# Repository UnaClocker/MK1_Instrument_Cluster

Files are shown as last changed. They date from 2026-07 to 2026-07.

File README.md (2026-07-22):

This code cannot be copyrighted, as it was entirely vibe coded via AI, Gemini to be specific. 
The circuit board was based on this design and physically made to fit with STL files which are included. The circuit board is licensed Creative Commons - Attribution.
The STLs were created by me, by hand, in TinkerCAD. They are licensed Create Commons - Attribution.

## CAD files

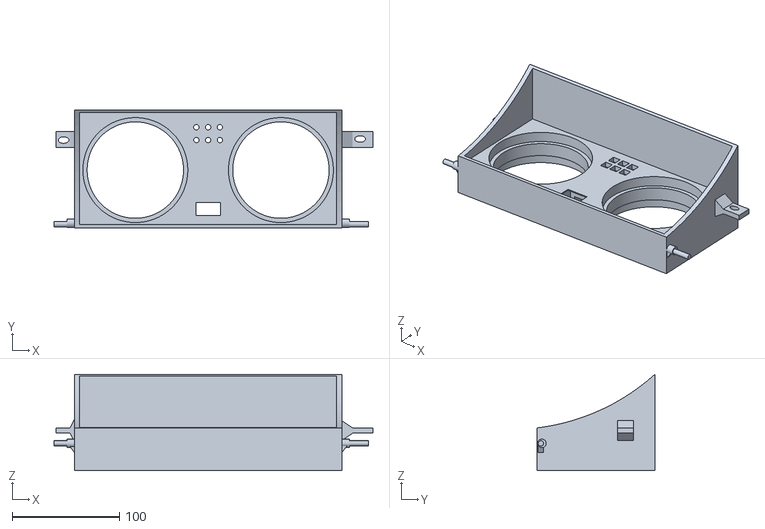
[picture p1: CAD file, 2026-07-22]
MK1 Instrument Cluster (6).stl
298.0 x 110.0 x 90.0

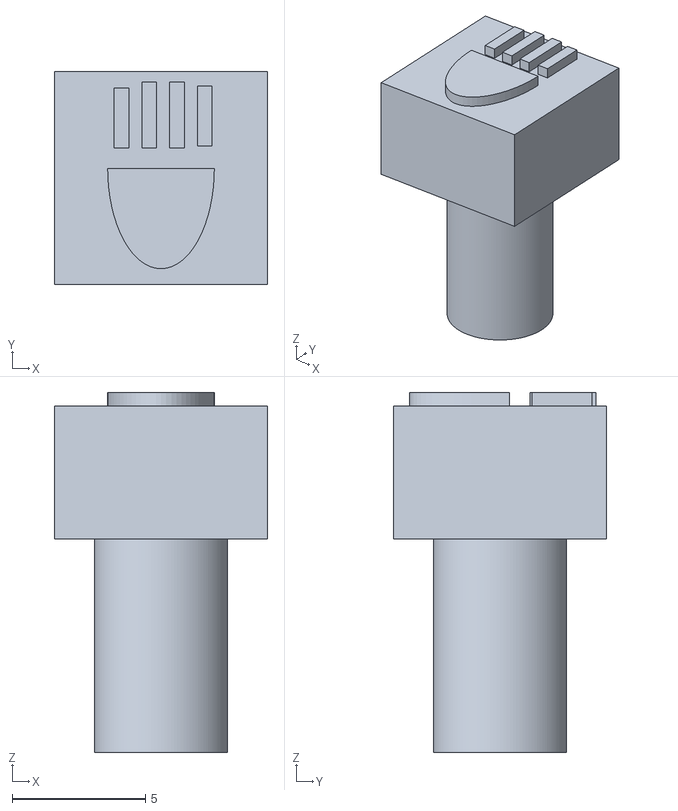
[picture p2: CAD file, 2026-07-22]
High_Beam_Indicators.stl
8.00 x 8.00 x 13.5

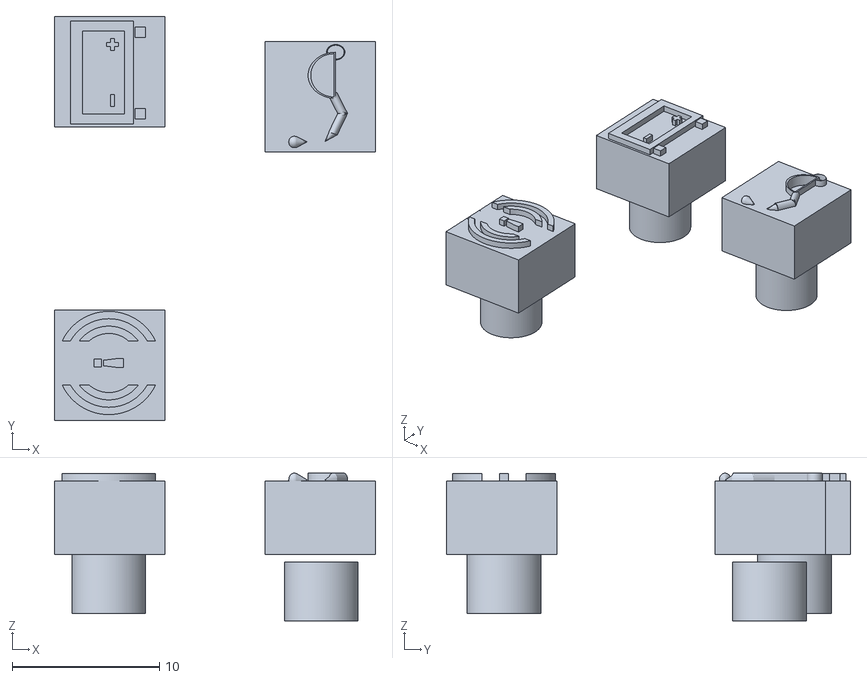
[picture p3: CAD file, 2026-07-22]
Warning_Indicators.stl
21.8 x 27.4 x 10.0

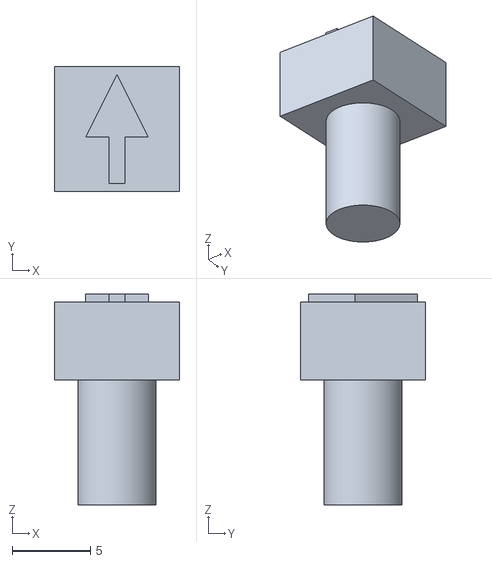
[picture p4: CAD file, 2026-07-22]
Blinker_Indicator.stl
8.00 x 8.00 x 13.5

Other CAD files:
Glowplug_Indicators.stl

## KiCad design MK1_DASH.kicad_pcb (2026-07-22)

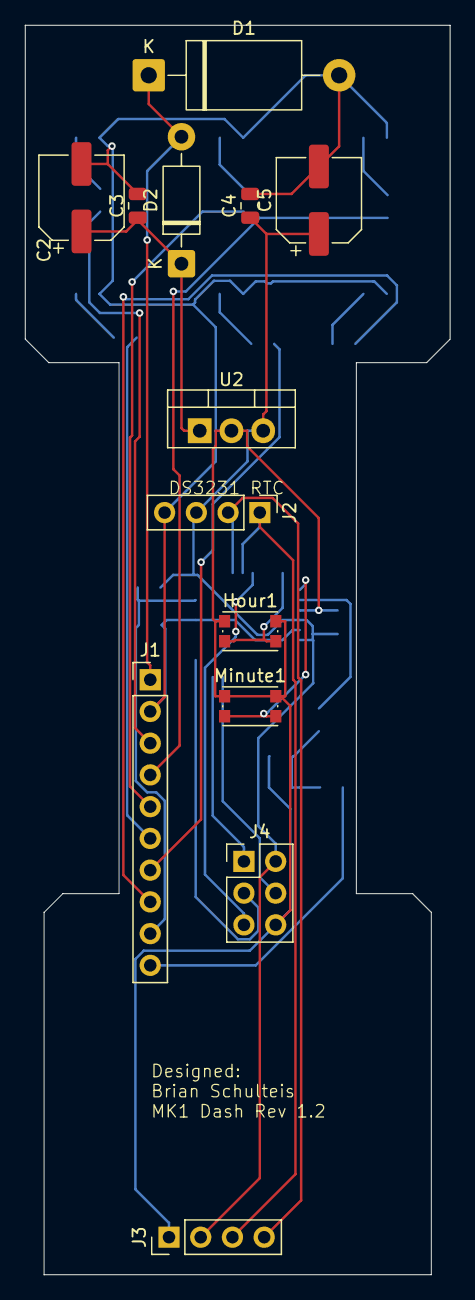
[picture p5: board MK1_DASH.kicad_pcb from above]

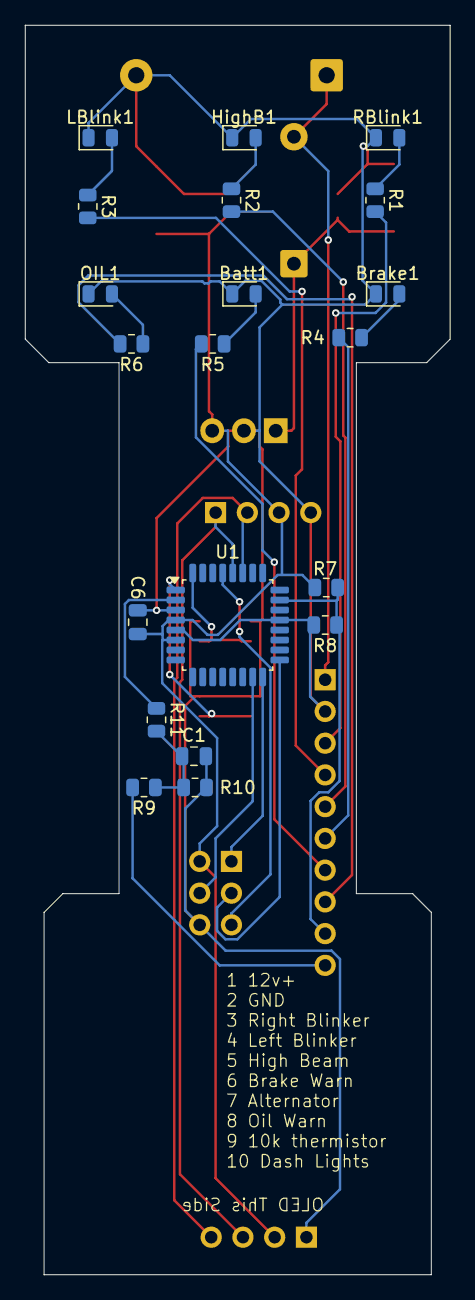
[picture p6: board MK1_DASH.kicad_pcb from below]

Board: 2 copper layers, 34.0 x 100.0 mm, 33 parts (20 on the bottom side), 28 nets.

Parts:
Batt1: LED; LED_0805_2012Metric
Brake1: LED; LED_0805_2012Metric
C1, C3, C4, C6: .1uF; C_0805_2012Metric
C2: 50uF 50v; CP_Elec_6.3x4.5
C5: 10uF 16v; CP_Elec_6.3x4.5
D1: SA18A; D_DO-201AE_P15.24mm_Horizontal
D2: 1N4007; D_DO-41_SOD81_P10.16mm_Horizontal
HighB1: LED; LED_0805_2012Metric
Hour1: SW_Push; SW_Push_1P1T_NO_CK_KMR2
J1: Conn_01x10; PinHeader_1x10_P2.54mm_Vertical
J2: RTC; PinHeader_1x04_P2.54mm_Vertical
J3: OLED; PinHeader_1x04_P2.54mm_Vertical
J4: AVR-ISP-6; PinHeader_2x03_P2.54mm_Vertical
LBlink1: LED; LED_0805_2012Metric
Minute1: SW_Push; SW_Push_1P1T_NO_CK_KMR2
OIL1: LED; LED_0805_2012Metric
R1, R2, R3: 4.7K; R_0805_2012Metric
R4, R5, R6: 3.3K; R_0805_2012Metric
R7, R8, R9: 10k; R_0805_2012Metric
R10: 4.7k; R_0805_2012Metric
R11: 1k; R_0805_2012Metric
RBlink1: LED; LED_0805_2012Metric
U1: ATmega328-A; TQFP-32_7x7mm_P0.8mm
U2: LM7805_TO220; TO-220-3_Vertical

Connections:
/Alternator: J1.7, R5.2
/Battery +: D1.1 (A1), D2.2 (A), J1.1
/Brake: J1.6, R4.2
/Dim: R11.1, U1.2 (PD4)
/High Beam: J1.5, R2.2
/Hour: Hour1.2, U1.32 (PD2)
/L Blinker: J1.4, R3.2
/MISO: J4.1 (MISO), U1.16 (PB4)
/MOSI: J4.4 (MOSI), U1.15 (PB3)
/Minute: Minute1.2, U1.1 (PD3)
/Oil: J1.8, R6.2
/Parking Lights: J1.10, R9.2
/R Blinker: J1.3, R1.2
/RST: J4.5 (~RST), U1.29 (~RESET/PC6)
/SCK: J4.3 (SCK), U1.17 (PB5)
/SCL: J2.1, J3.3, U1.28 (PC5)
/SDA: J2.2, J3.4, U1.27 (PC4)
/Temp: J1.9, R7.1, R8.1, U1.23 (PC0)
GND: Batt1.1 (K), Brake1.1 (K), C1.2, C2.2, C3.2, C4.2, C5.2, C6.2, D1.2 (A2), HighB1.1 (K), Hour1.1, J1.2, J2.4, J3.1, J4.6 (GND), LBlink1.1 (K), Minute1.1, OIL1.1 (K), R8.2, R10.2, RBlink1.1 (K), U1.3 (GND), U1.5 (GND), U1.21 (GND), U2.2 (GND)
unnamed: Batt1.2 (A), R5.1
unnamed: Brake1.2 (A), R4.1
unnamed: C1.1, R9.1, R10.1, R11.2
unnamed: C2.1, C3.1, D2.1 (K), U2.1 (VI)
unnamed: HighB1.2 (A), R2.1
unnamed: LBlink1.2 (A), R3.1
unnamed: OIL1.2 (A), R6.1
unnamed: R1.1, RBlink1.2 (A)
VCC: C4.1, C5.1, C6.1, J2.3, J3.2, J4.2 (VCC), R7.2, U1.4 (VCC), U1.6 (VCC), U2.3 (VO)

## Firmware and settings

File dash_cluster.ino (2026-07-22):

#include <Wire.h>
#include <U8g2lib.h>
#include <RTClib.h>

// U8G2_R2 flips the display 180 degrees
U8G2_SSD1306_128X64_NONAME_F_HW_I2C u8g2(U8G2_R2, /* reset=*/ U8X8_PIN_NONE);

// Initialize the DS3231 RTC
RTC_DS3231 rtc;

// Hardware Pins
const int BTN_HOUR = 2;
const int BTN_MIN = 3;
const int PIN_DIM = 4; // NEW: Low = Dim (1), High = Bright (255)

// Thermistor Parameters
const int THERMISTOR_PIN = A0;
const float SERIES_RESISTOR = 10000.0; 
const float NOMINAL_RESISTANCE = 10000.0; 
const float NOMINAL_TEMPERATURE = 25.0; 
const float B_COEFFICIENT = 3950.0; 
const float ADC_MAX = 1023.0;

// Timing Variables
unsigned long lastTempRead = 0;
const unsigned long tempInterval = 10000; // Read temp every 10 seconds
float currentTempF = 0.0;

// Time Modification Variables
bool isSettingTime = false;
unsigned long lastButtonPressTime = 0;
const unsigned long saveTimeout = 10000; 

// In-memory clock state for editing
int editHour = 0;
int editMinute = 0;
int editSecond = 0;
int editYear = 2026;
int editMonth = 7;
int editDay = 14;

// Simple state tracking for debouncing buttons and dimming
bool lastHourState = HIGH;
bool lastMinState = HIGH;
int currentBrightness = 255;

void setup() {
  pinMode(BTN_HOUR, INPUT_PULLUP);
  pinMode(BTN_MIN, INPUT_PULLUP);
  
  // NEW: Configure dimming pin with an internal pull-up.
  // If left unconnected, it stays HIGH (bright). Grounding this pin triggers dim state.
  pinMode(PIN_DIM, INPUT_PULLUP);

  u8g2.begin();

  Wire.setClock(100000);

  // Show the VW Splash Screen for 3 seconds on startup
  showVWSplashScreen();
}

void loop() {
  unsigned long currentMillis = millis();

  // 1. Handle Dimming Input
  // If PIN_DIM is pulled LOW (active), dim the screen to 1. Otherwise, keep it at 255.
  int targetBrightness = (digitalRead(PIN_DIM) == LOW) ? 1 : 255;
  if (targetBrightness != currentBrightness) {
    currentBrightness = targetBrightness;
    if (targetBrightness==255) {
      setNormalBright();
    } else {
      setUltraDim();
    }
  }

  // 2. Read temperature at defined intervals
  if (currentMillis - lastTempRead >= tempInterval || lastTempRead == 0) {
    lastTempRead = currentMillis;
    currentTempF = readTemperatureF();
  }

  // 3. Fetch the current time
  int displayHour = 0;
  int displayMinute = 0;

  if (!isSettingTime) {
    DateTime now = rtc.now();
    displayHour = now.hour();
    displayMinute = now.minute();
  } else {
    displayHour = editHour;
    displayMinute = editMinute;

    if (currentMillis - lastButtonPressTime >= saveTimeout) {
      rtc.adjust(DateTime(editYear, editMonth, editDay, editHour, editMinute, 0));
      isSettingTime = false;
    }
  }

  // 4. Scan Buttons (Active Low - pressed is LOW)
  bool currentHourState = digitalRead(BTN_HOUR);
  bool currentMinState = digitalRead(BTN_MIN);

  if (currentHourState == LOW && lastHourState == HIGH) {
    delay(50); 
    if (digitalRead(BTN_HOUR) == LOW) {
      if (!isSettingTime) {
        enterEditMode();
      }
      editHour = (editHour + 1) % 24; 
      lastButtonPressTime = currentMillis;
    }
  }

  if (currentMinState == LOW && lastMinState == HIGH) {
    delay(50); 
    if (digitalRead(BTN_MIN) == LOW) {
      if (!isSettingTime) {
        enterEditMode();
      }
      editMinute = (editMinute + 1) % 60; 
      lastButtonPressTime = currentMillis;
    }
  }

  lastHourState = currentHourState;
  lastMinState = currentMinState;

  // 5. Render Layout (Page Buffer Mode)
  u8g2.clearBuffer();
  
    // ----------------------------------------------------
    // Draw Corner Temperature (Top-Right)
    // ----------------------------------------------------
    u8g2.setFont(u8g2_font_7x14_tr); // Large 14px font
    char tempBuffer[8];
    dtostrf(currentTempF, 2, 0, tempBuffer);
    strcat(tempBuffer, "F");
    
    u8g2.drawStr(104, 13, tempBuffer);
    u8g2.drawCircle(98, 5, 1); // Aligned degree symbol

    // If setting time, draw an indicator on the screen
    if (isSettingTime) {
      u8g2.setFont(u8g2_font_5x7_tr); 
      u8g2.drawStr(4, 8, "SET TIME");
    }

    // ----------------------------------------------------
    // Draw Centered Time (HH:MM)
    // ----------------------------------------------------
    u8g2.setFont(u8g2_font_logisoso42_tn);
    char timeBuffer[6];
    
    int amPmHour = displayHour;
    if (amPmHour == 0) {
      amPmHour = 12;
    } else if (amPmHour > 12) {
      amPmHour -= 12;
    }

    sprintf(timeBuffer, "%d:%02d", amPmHour, displayMinute);

    int textWidth = u8g2.getStrWidth(timeBuffer);
    int xPos = (128 - textWidth) / 2;
    int yPos = 60; // Perfectly aligned to the bottom edge

    u8g2.drawStr(xPos, yPos, timeBuffer);

  u8g2.sendBuffer();
  delay(10); 
}

// Renders a perfectly proportioned vector VW logo centered on the 128x64 display
void showVWSplashScreen() {
  const int centerX = 64;
  const int centerY = 32;
  const int outerRadius = 28;

  u8g2.clearBuffer(); // Clear the full buffer once

  // Draw outer double-ring emblem
  u8g2.drawCircle(centerX, centerY, outerRadius);
  u8g2.drawCircle(centerX, centerY, outerRadius - 2);

  // ----------------------------------------------------
  // --- "V" Section (Strictly Top Half: Y: 10 to 30) ---
  // ----------------------------------------------------
  u8g2.drawLine(centerX - 12, centerY - 20, centerX - 2, centerY - 2);
  u8g2.drawLine(centerX - 11, centerY - 20, centerX - 1, centerY - 2);
  u8g2.drawLine(centerX + 12, centerY - 20, centerX + 2, centerY - 2);
  u8g2.drawLine(centerX + 11, centerY - 20, centerX + 1, centerY - 2);

  // ----------------------------------------------------
  // --- Horizontal Split (Gap between V and W) ---------
  // ----------------------------------------------------
  u8g2.setDrawColor(0);
  u8g2.drawHLine(centerX - 24, centerY - 1, 48);
  u8g2.drawHLine(centerX - 24, centerY, 48);
  u8g2.setDrawColor(1);

  // ----------------------------------------------------
  // --- "W" Section (Strictly Bottom Half: Y: 33 to 53) ---
  // ----------------------------------------------------
  u8g2.drawLine(centerX - 18, centerY + 2, centerX - 9, centerY + 20);
  u8g2.drawLine(centerX - 17, centerY + 2, centerX - 8, centerY + 20);
  u8g2.drawLine(centerX - 9, centerY + 20, centerX - 1, centerY + 2);
  u8g2.drawLine(centerX - 8, centerY + 20, centerX - 1, centerY + 3);
  u8g2.drawLine(centerX + 9, centerY + 20, centerX + 1, centerY + 2);
  u8g2.drawLine(centerX + 8, centerY + 20, centerX + 1, centerY + 3);
  u8g2.drawLine(centerX + 18, centerY + 2, centerX + 9, centerY + 20);
  u8g2.drawLine(centerX + 17, centerY + 2, centerX + 8, centerY + 20);

  u8g2.sendBuffer(); // Push the whole logo to the screen at once

  // Hold the logo on the screen for 3000ms (3 seconds)
  delay(3000);
}

void enterEditMode() {
  DateTime now = rtc.now();
  editHour = now.hour();
  editMinute = now.minute();
  editSecond = 0;
  editYear = now.year();
  editMonth = now.month();
  editDay = now.day();
  isSettingTime = true;
}

float readTemperatureF() {
  int analogVal = analogRead(THERMISTOR_PIN);
  if (analogVal == 0) return 0.0;
  
  float resistance = ADC_MAX / (float)analogVal - 1.0;
  resistance = SERIES_RESISTOR / resistance;
  
  float steinhart;
  steinhart = resistance / NOMINAL_RESISTANCE;     
  steinhart = log(steinhart);                      
  steinhart /= B_COEFFICIENT;                      
  steinhart += 1.0 / (NOMINAL_TEMPERATURE + 273.15); 
  steinhart = 1.0 / steinhart;                     
  steinhart -= 273.15;                             
  
  return (steinhart * 9.0 / 5.0) + 32.0;
}

void setUltraDim() {
  u8g2.setContrast(1); // Drop master contrast to minimum
  
  // Send raw commands to the SSD1306 controller
  u8g2.sendF("c", 0xD9); // Set Pre-Charge Period
  u8g2.sendF("c", 0x22); // Minimum pre-charge phase (Default is usually 0x22 or 0xF1)
  
  u8g2.sendF("c", 0xDB); // Set VCOMH Deselect Level
  u8g2.sendF("c", 0x10); // Set to lowest voltage level (0.65 x Vcc)
}

void setNormalBright() {
  u8g2.setContrast(255); // Restore master contrast
  
  // Restore default pre-charge and VCOMH levels
  u8g2.sendF("c", 0xD9);
  u8g2.sendF("c", 0xF1); 
  
  u8g2.sendF("c", 0xDB);
  u8g2.sendF("c", 0x20); 
}
